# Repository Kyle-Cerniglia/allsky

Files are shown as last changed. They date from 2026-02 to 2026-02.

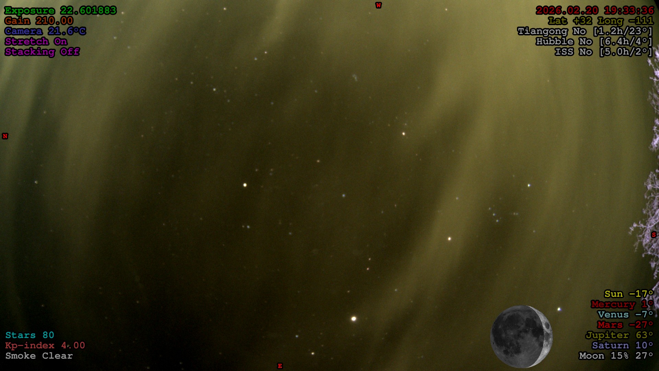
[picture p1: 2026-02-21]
Photos/allsky cloudcover.jpg

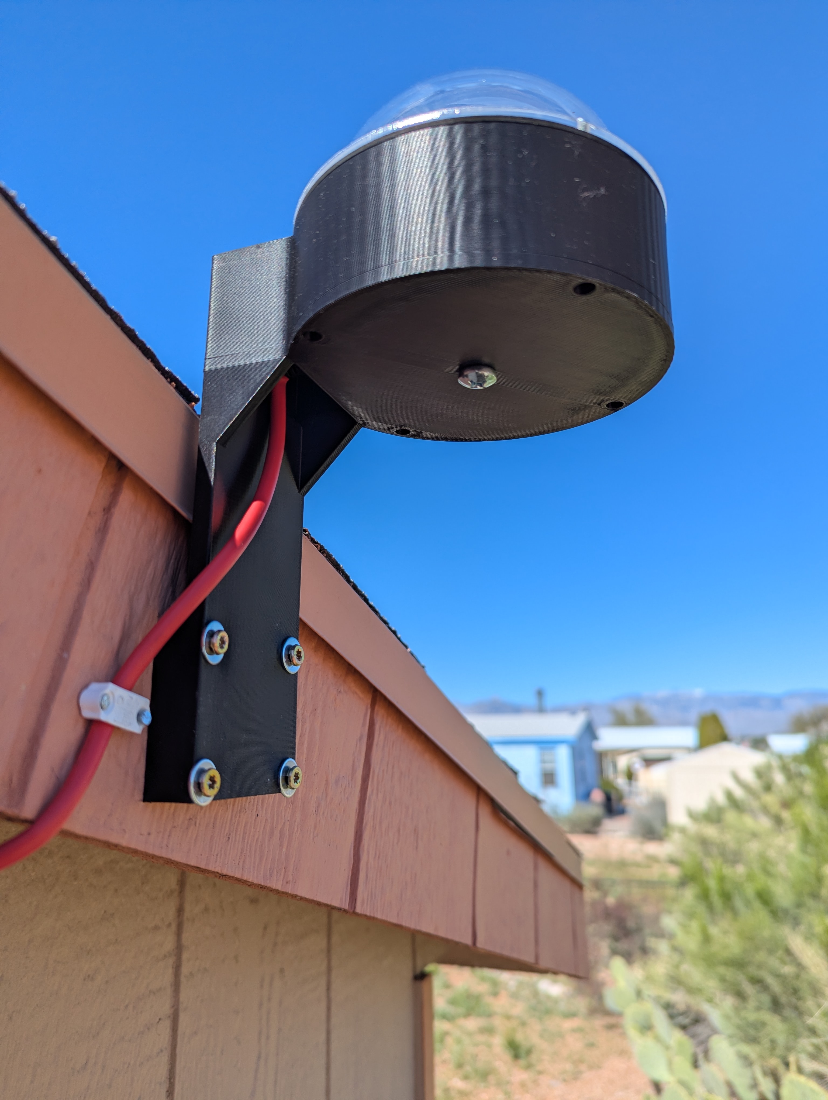
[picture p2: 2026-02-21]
Photos/allsky bottom.jpg

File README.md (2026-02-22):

ALLSKY CAMERA REPO OVERVIEW

This repository contains CAD files for creating your own mount for an outdoor sky camera using a ZWO planetary camera, intended for use with the INDI-Allsky software (https://github.com/aaronwmorris/indi-allsky).

FILE INDEX:

CAD Files\Allsky Camera (Assembly) v9.step:
STEP file for the whole assembly to visualize assembly

CAD Files\Allsky Camera Base v10.step:
STEP file for the main housing, if it needs to be modified for the user

CAD Files\dome seal v1.step:
STEP file for the rubber gasket to seal the dome

Fabrication Files\Allsky Camera Base v10.stl:
STL file of the main housing, ready for 3D printing

Fabrication Files\dome seal v1.dxf:
DXF files of the rubber gasket for laser cutting or stenciling

Photos\:
Folder of various photos of the system

BILL OF MATERIALS
- 1x Allsky Camera Base (3D printed from file, ASA plastic recommended)
- 1x Dome Seal (Laser cut from 1.5mm rubber, or cut with a knife)
- 4x 4-40 1/2" Screw (McMaster-Carr 91772A110 or similar)
- 4x 4-40 Nut (McMaster-Carr 91841A005 or similar)
- 1x 1/4-20 1/2" Screw (McMaster-Carr 91772A537 or similar)
- 1x ZWO ASI662MC Planetary Camera (Alternatively, the ASI676MC has a larger square sensor with an UV/IR filter, but is twice the cost)
- 1x ZWO 170° 2.5mm CS Lens (The ASI662MC does come with a 150° 2.1mm lens, but this one is better)
- 1x Raspberry Pi 4B 4GB (Or better)
- 1x MicroSD card 128GB (Or better)
- 1x Acrylic Dome (Amazon https://www.amazon.com/dp/B07L6GLTNP)
- 1x Rubber Sheet (McMaster-Carr 85785K23 or similar)
- 4x Generic Wood Screws with Washers

PI Setup
- Download Raspberry Pi OS (64-bit Trixie) to your PC from here (https://www.raspberrypi.com/software/operating-systems/). The Lite version can be used for headless operation, or the full version can be used with a GUI
- Install the Raspberry Pi Imager onto your PC from here (https://www.raspberrypi.com/software/)
- Connect the MicroSD card to your PC, and flash the card with the OS using the Raspberry Pi Imager
- Install the MicroSD card in your PI, connect the PI to a monitor, mouse and keyboard, ethernet (Optional, can use WiFi instead), and apply power
- Follow the OS installation instructions
- Install git> sudo apt-get install git
- Clone the INDI-Allsky repo> git clone https://github.com/aaronwmorris/indi-allsky.git
- Navigate to the directory> cd indi-allsky/misc/
- Manually build the application from source and follow the on screen instructions (This takes awhile)> ./build_indi.sh
- Naviagate to the top folder> cd ../
- Install the application, and follow the on screen instructions (Enabling autostart on boot is recommended)> ./setup.sh
- If nothing failed, it should be running the hosted website you can navigate to for viewing the camera and configuring the system. You can check your PI's IP address with> ifconfig

ASSEMBLY
- Print the Allsky Camera Base
- Cut the rubber gasket from the rubber sheet
- Connect the camera to its USB cable, and feed the cable through the hole in the bottom/side of the base, seat the camera in its pocket (The cable will be a bit of a tight squeeze, careful that you don't bend it or the USB port too much)
- Using the 1/4-20 screw, thread it into the center hole on the bottom of the base, screwing into the camera to secure it
- Remove the 2.1mm lens that shipped with the camera, and install the 2.5mm lens
- Using the wood screws and washers, mount this to the side of your house/shed or other mounting method
- Once the PI is setup and running, rotate the lens until focus is achieved
- Using the 4-40 screws, insert them into the 4 holes around the edge of the dome from the bottom
- Slide the gasket onto the 4 screws protruding from the bottom
- Slide the dome over the gasket onto the 4 screws protruding from the bottom
- Secure the 4 screws with their nuts

MISC NOTES
- This camera does NOT have an IR filter, so ensure that there are no security cameras with IR lights pointing at it

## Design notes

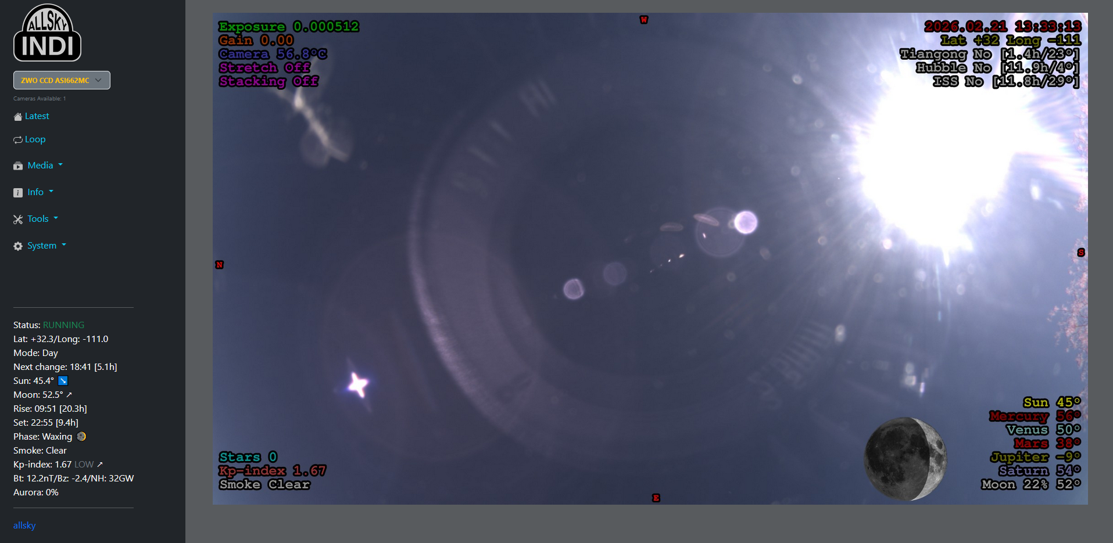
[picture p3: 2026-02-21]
Photos/allsky web interface.png

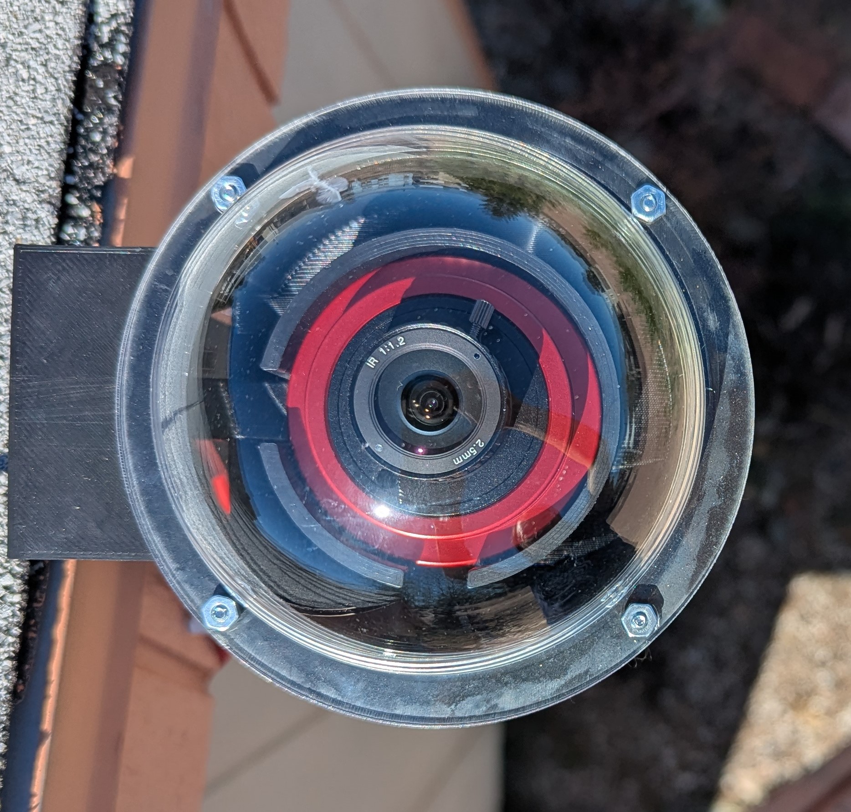
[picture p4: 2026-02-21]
Photos/allsky top.jpg

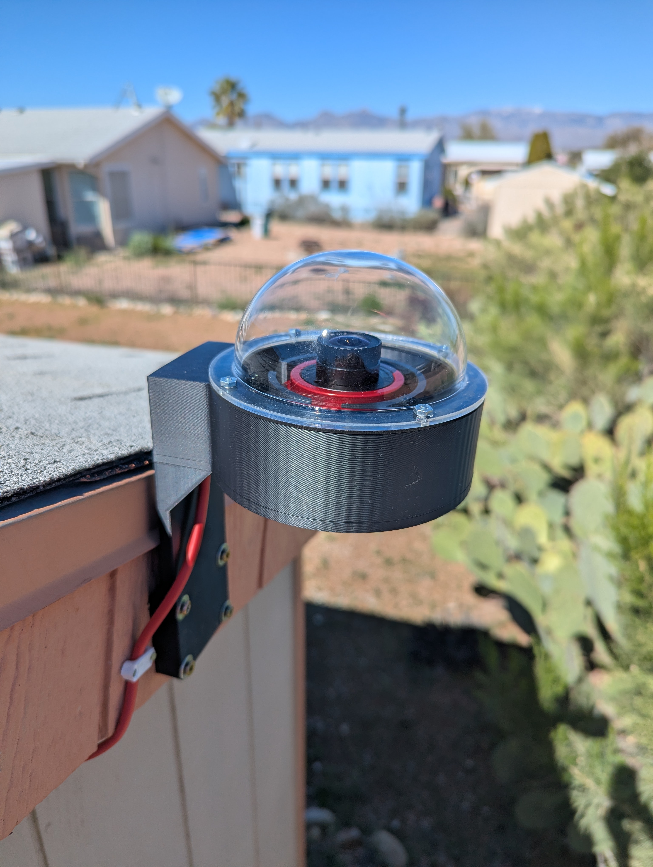
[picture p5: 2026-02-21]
Photos/allsky camera.jpg

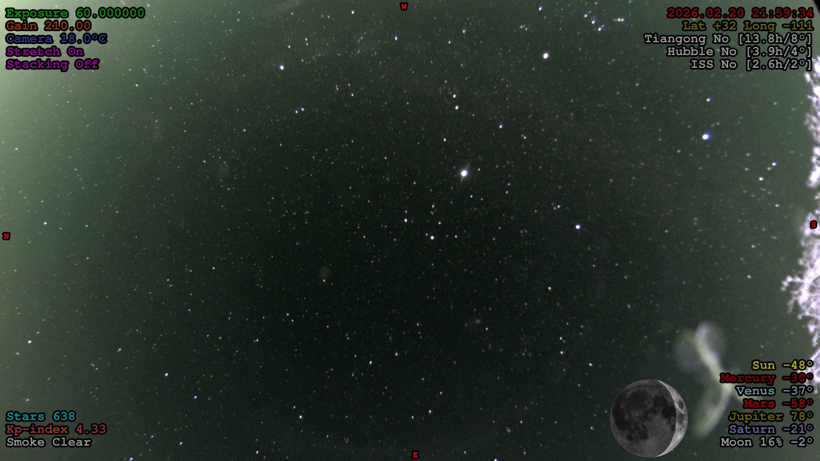
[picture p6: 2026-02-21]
Photos/allsky nightscape.jpg

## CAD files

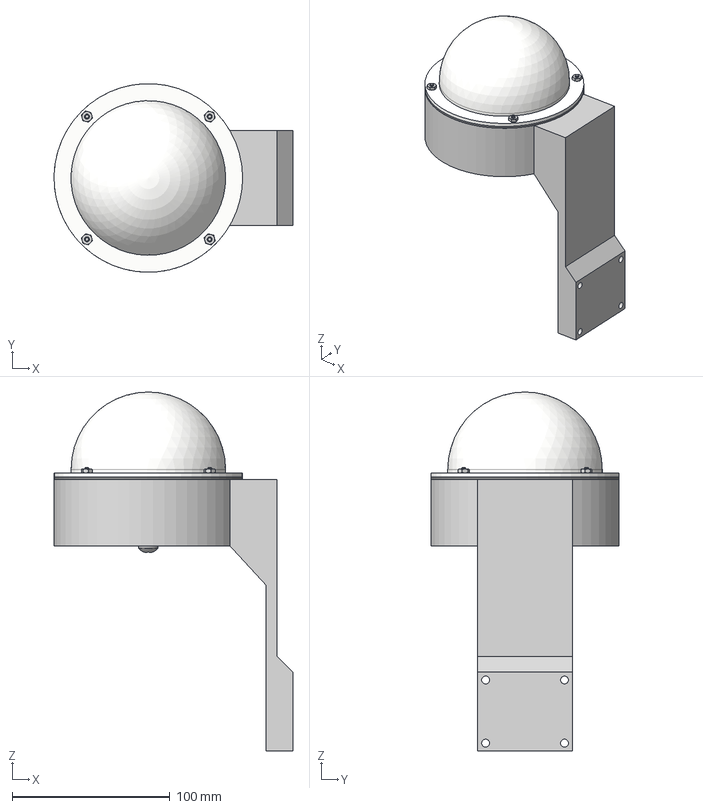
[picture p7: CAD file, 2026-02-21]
CAD Files/Allsky Camera (Assembly) v10.step
151.4 x 119.4 x 227.5 mm
Allsky Camera Base
dome seal
ASI662
Dome
91841A005_Corrosion-Resistant 18-8 Stainless Steel Hex Nuts x 4
91772A110_Passivated 18-8 Stainless Steel Pan Head Phillips Screw x 4
91772A537_Passivated 18-8 Stainless Steel Pan Head Phillips Screw

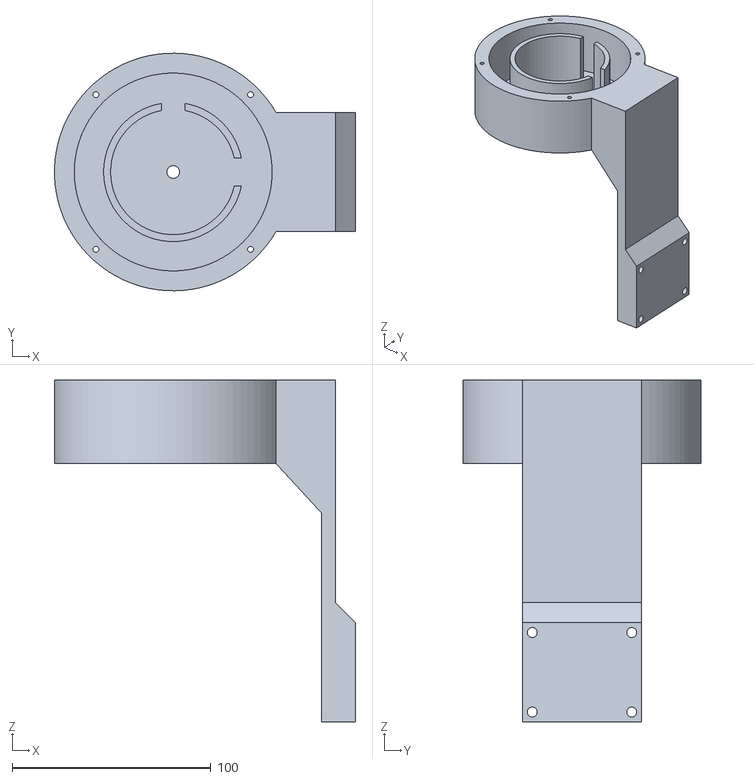
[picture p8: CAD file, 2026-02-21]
Fabrication Files/Allsky Camera Base v10.stl
151.4 x 119.5 x 172.0

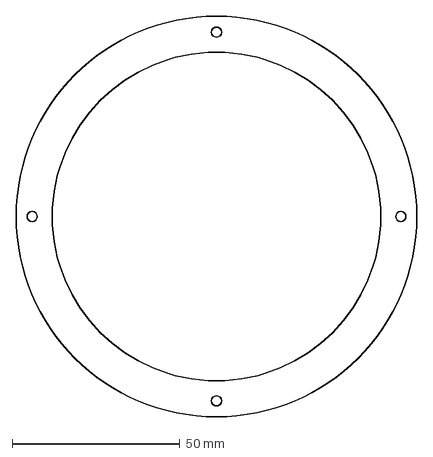
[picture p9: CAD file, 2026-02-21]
Fabrication Files/dome seal v1.dxf
119.5 x 119.5 mm

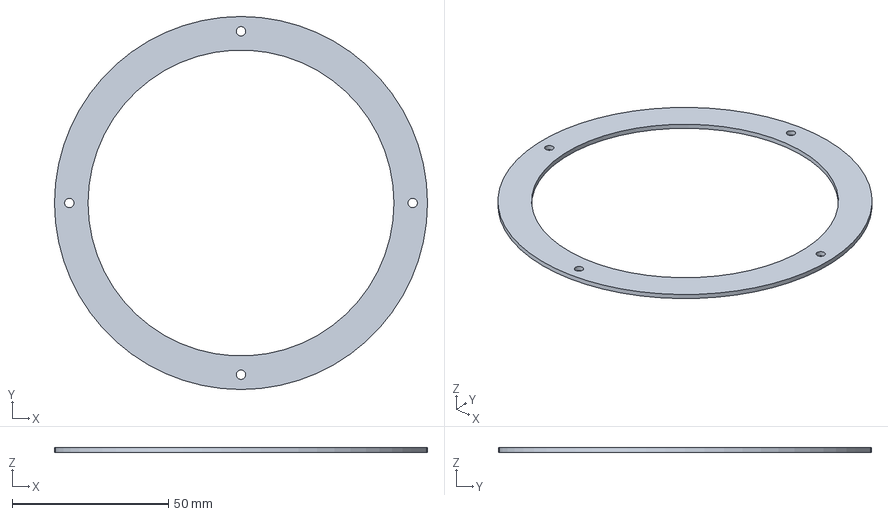
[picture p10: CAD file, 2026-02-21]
CAD Files/dome seal v1.step
119.5 x 119.5 x 1.50 mm

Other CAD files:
CAD Files/Allsky Camera Base v10.step
CAD Files/Allsky Camera (Assembly) v9.step

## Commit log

2026-02-21 added cad files
    [Allsky Camera (Assembly).step, Allsky Camera Base.step, dome seal.step]
2026-02-21 added fabrication files, added folders, started readme
    [Allsky Camera (Assembly) v9.step, Allsky Camera Base v10.step, Allsky Camera Base v10.stl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]
2026-02-21 updated lens length
    [Allsky Camera (Assembly) v10.step]
2026-02-22 added note about the ASI676 camera
